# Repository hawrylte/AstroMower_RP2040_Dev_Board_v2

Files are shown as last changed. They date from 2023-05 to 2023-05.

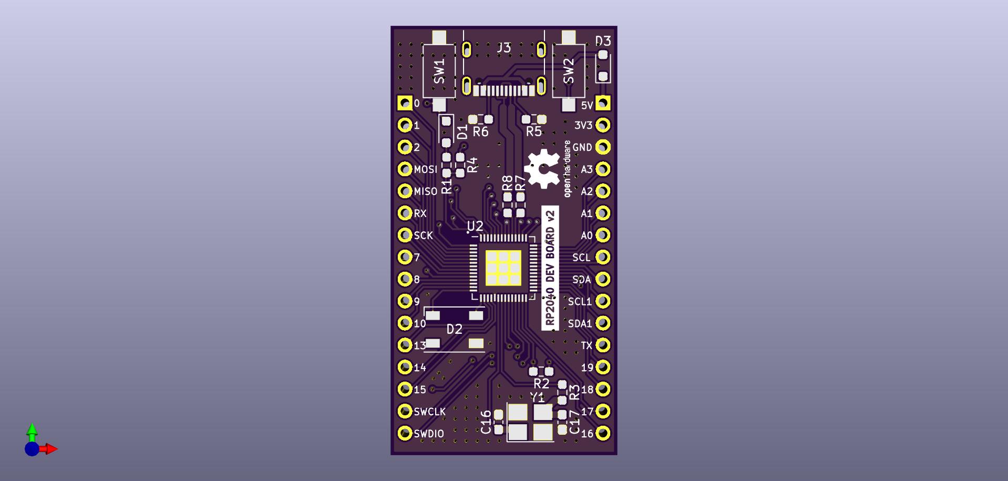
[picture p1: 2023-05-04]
images/RP2040_DevBoard_v2_front.jpg

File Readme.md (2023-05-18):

# AstroMower RP2040 Dev Board v2
## About
RP2040 Development Board to explore programming capability of Raspberry Pi [RP2040](https://www.raspberrypi.com/products/rp2040/) MCU for use in future projects.

## Hardware
  * 2 Layer PCB with parts populated on both sides

  * Spacing of pin headers is 0.9" to use on standard breadboard.

  * PCB Overall Dimensions 1.05" W X 1.95" L

  * USB-C Interface

  * Resistor and Capacitor sizes are 0603 and 0805 with hand solder footprints

  * Incorporates Neopixel addressable LED

  * 8 MB QSPI Flash

  * All parts ordered through Digi-Key

  * Developed in [KiCad 7.0](https://www.kicad.org/)

  * DRC for Manufacture through [OSHPARK](https://oshpark.com/)

## Software
### ***SOFTWARE UNDER DEVELOPMENT***
### MicroPython
MicroPython firmware for board can be downloaded directly or built from source.

***Instructions for building from source on Debian based system***

Building from source requires MicroPython source. Installation of this mirrors instructions found in Raspberry Pi [Raspberry Pi Pico Python SDK](https://datasheets.raspberrypi.com/pico/raspberry-pi-pico-python-sdk.pdf)

Create *pico* directory
```
mkdir pico
cd pico
```
Then clone the *micropython* git repository
```
git clone https://github.com/micropython/micropython.git --branch master
```
Fetch additional submodules required for a RP2 MCU board
```
cd micropython
make -C port/rp2 submodules
```
To build *micropython* additional tools are required
```
sudo apt update
sudo apt install cmake gcc-arm-none-eabi libnewlib-arm-none-eabi build-essential libstdc++-arm-none-eabi-newlib
```
Bootstrap a special tool for MicroPython builds
```
make -C mpy-cross
```
***Load Board Specific Files for AstroMower Board***

Download *AstroMower RP2040 Dev Board v2* git repository
```
cd ..
git clone https://github.com/hawrylte/AstroMower_RP2040_Dev_Board_v2.git
```
Move specific board files to proper locations in *MicroPython* source files
```
cp -r AstroMower_RP2040_Dev_Board_v2/src/ASTROMOWER_RP2040_DEV_BOARD_V2 micropython/ports/rp2/boards/ASTROMOWER_RP2040_DEV_BOARD_V2
cp -r AstroMower_RP2040_Dev_Board_v2/src/astromower_rp2040_dev_board_v2.h micropython/lib/pico-sdk/src/boards/include/boards/astromower_rp2040_dev_board_v2.h
```
Build the port we need for RP2040 and specify our particular board to be built
```
cd micropython/ports/rp2
make BOARD=ASTROMOWER_RP2040_DEV_BOARD_V2
```
Copy UF2 Firmware from *MicroPython* build directory to *pico* directory
```
cd ../../..
cp micropython/ports/rp2/build-ASTROMOWER_RP2040_DEV_BOARD_V2/firmware.uf2 AstroMower_RP2040_Dev_Board_MicroPython_firmware.uf2
```
### C/C++

***Instructions for setting up PICO-SDK from source on Debian based system***

Setting up the *pico-sdk* mirrors instructions found in Raspberry Pi [Gettting Stated with Raspberry Pi Pico](https://datasheets.raspberrypi.com/pico/getting-started-with-pico.pdf)

Create *pico* directory
```
mkdir pico
cd pico
```
Then clone the *pico-sdk* and the *pico-examples* git repositories
```
git clone http://github.com/raspberrypi/pico-sdk.git --branch master
cd pico-sdk
git submodule update --init
cd ..
git clone http://github.com/raspberrypi/pico-examples.git --branch master
```
To build *pico-examples* additional tools are required
```
sudo apt update
sudo apt install cmake gcc-arm-none-eabi libnewlib-arm-none-eabi build-essentials libstdc++-arm-none-eabi-newlib
```
Download *AstroMower RP2040 Dev Board v2* git repositiry
```
git clone https://github.com/hawrylte/AstroMower_RP2040_Dev_Board_v2.git
```
Move specific board files to proper locations in *pico-sdk* source files
```
cp -r AstroMower_RP2040_Dev_Board_v2/src/astromower_rp2040_dev_board_v2.h pico-sdk/src/boards/include/boards/astromower_rp2040_dev_board_v2.h
```
***Instructions for building Blink example from PICO-EXAMPLES from source on Debian based system***

***AstroMower Dev Board v2 does not have a discrete LED for Blink to run, but this shows the process of building a C/C++ program for the AstroMower Dev Board v2***

Change to *pico-examples* directory and make *build* directory.
```
cd pico-examples
mkdir build
cd buid
```
Set *PICO_SDK_PATH*
```
export PICO-SDK-PATH=../../pico-sdk
```
Prepare cmke build directory and identify board to build program for.
```
cmake .. -DPICO_BOARD=astromower_rp2040_dev_board_v2
cd blink
make -j4
```
*blink.elf* is used by the debugger
*blink.uf2* is the program and can be dragged onto the RP2040 USB Mass Storage Device

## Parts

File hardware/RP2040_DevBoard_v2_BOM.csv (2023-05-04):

Reference | Value | Footprint | Datasheet | Digi-Key PN | Mfg PN | Qty
C1, C2, C7 | 1u | Capacitor_SMD:C_0603_1608Metric_Pad1.08x0.95mm_HandSolder | https://datasheets.kyocera-avx.com/X7RDielectric.pdf | 478-5010-2-ND | 0603YC105KAT2A | 3
C3-C6, C8-C13, C15 | 0.1u | Capacitor_SMD:C_0603_1608Metric_Pad1.08x0.95mm_HandSolder | https://datasheets.kyocera-avx.com/X7RDielectric.pdf | 478-7018-2-ND | 06033C104KAT4A | 11
C14, C18 | 10u | Capacitor_SMD:C_0805_2012Metric_Pad1.18x1.45mm_HandSolder | https://datasheets.kyocera-avx.com/X7RDielectric.pdf | 478-10578-2-ND | 0805ZC106KAT2A | 2
C16, C17 | 8p | Capacitor_SMD:C_0603_1608Metric_Pad1.08x0.95mm_HandSolder | https://datasheets.kyocera-avx.com/AutoMLCC.pdf | 478-9370-2-ND | 06031A8R0D4T2A | 2
D1, D3 | NSR0320 | Diode_SMD:D_SOD-323_HandSoldering | https://www.onsemi.com/pdf/datasheet/nsr0320mw2t1-d.pdf | NSR0320MW2T3GOSTR-ND | NSR0320MW2T3G | 2
D2 | WS2812B | RP2040_DevBoard:WS2812B | http://cdn.sparkfun.com/datasheets/BreakoutBoards/WS2812B.pdf | 1568-COM-16347TR-ND | COM-16347 | 1
J1, J2 | Conn_01x16 | Connector_PinHeader_2.54mm:PinHeader_1x16_P2.54mm_Vertical | https://app.adam-tech.com/products/download/data_sheet/201605/ph1-xx-ua-data-sheet.pdf | 2057-PH1-16-UA-ND | PH1-16-UA | 2
J3 | USB_C_Receptacle_USB2.0 | Connector_USB:USB_C_Receptacle_GCT_USB4105-xx-A_16P_TopMnt_Horizontal | https://media.digikey.com/pdf/Data%20Sheets/GCT%20PDFs/USB4105%20-%20Product%20Drawing.pdf | 2073-USB4105-GF-ATR-ND | USB4105-GF-A | 1
R1, R3 | 1k3 | Resistor_SMD:R_0603_1608Metric_Pad0.98x0.95mm_HandSolder | https://industrial.panasonic.com/cdbs/www-data/pdf/RDA0000/AOA0000C304.pdf | P1.30KHTR-ND | ERJ-3EKF1301V | 2
R2, R4 | 10k | Resistor_SMD:R_0603_1608Metric_Pad0.98x0.95mm_HandSolder | https://industrial.panasonic.com/cdbs/www-data/pdf/RDA0000/AOA0000C304.pdf | P10.0KHTR-ND | ERJ-3EKF1002V | 2
R5, R6 | 5k1 | Resistor_SMD:R_0603_1608Metric_Pad0.98x0.95mm_HandSolder | https://industrial.panasonic.com/cdbs/www-data/pdf/RDA0000/AOA0000C304.pdf | P5.10KHTR-ND | ERJ-3EKF5101V | 2
R7, R8 | 27 | Resistor_SMD:R_0603_1608Metric_Pad0.98x0.95mm_HandSolder | https://industrial.panasonic.com/cdbs/www-data/pdf/RDA0000/AOA0000C304.pdf | P27.0HTR-ND | ERJ-3EKF27R0V | 2
SW1, SW2 | PTS636 SK25 | Button_Switch_SMD:SW_SPST_CK_RS282G05A3 | https://www.ckswitches.com/media/2779/pts636.pdf | CKN12322-2-ND | PTS636 SK25 SMTR LFS | 2
U1 | AP2112K-3.3 | Package_TO_SOT_SMD:SOT-23-5 | https://www.diodes.com/assets/Datasheets/AP2112.pdf | AP2112K-3.3TRG1DITR-ND | AP2112K-3.3TRG1 | 1
U2 | RP2040 | Package_DFN_QFN:QFN-56-1EP_7x7mm_P0.4mm_EP4x4mm | https://datasheets.raspberrypi.com/rp2040/rp2040-datasheet.pdf | 2648-SC0914(13)TR-ND | SC0914(13) | 1
U3 | W25Q64JVSS | Package_SO:SOIC-8_5.23x5.23mm_P1.27mm | https://www.winbond.com/resource-files/w25q64jv%20revj%2003272018%20plus.pdf | W25Q64JVSSIQ-ND | W25Q64JVSSIQ | 1
Y1 | 12MHz | Crystal:Crystal_SMD_3225-4Pin_3.2x2.5mm_HandSoldering | https://www.we-online.com/catalog/datasheet/830108206909.pdf | 1923-830108206909TR-ND | 830108206909 | 1

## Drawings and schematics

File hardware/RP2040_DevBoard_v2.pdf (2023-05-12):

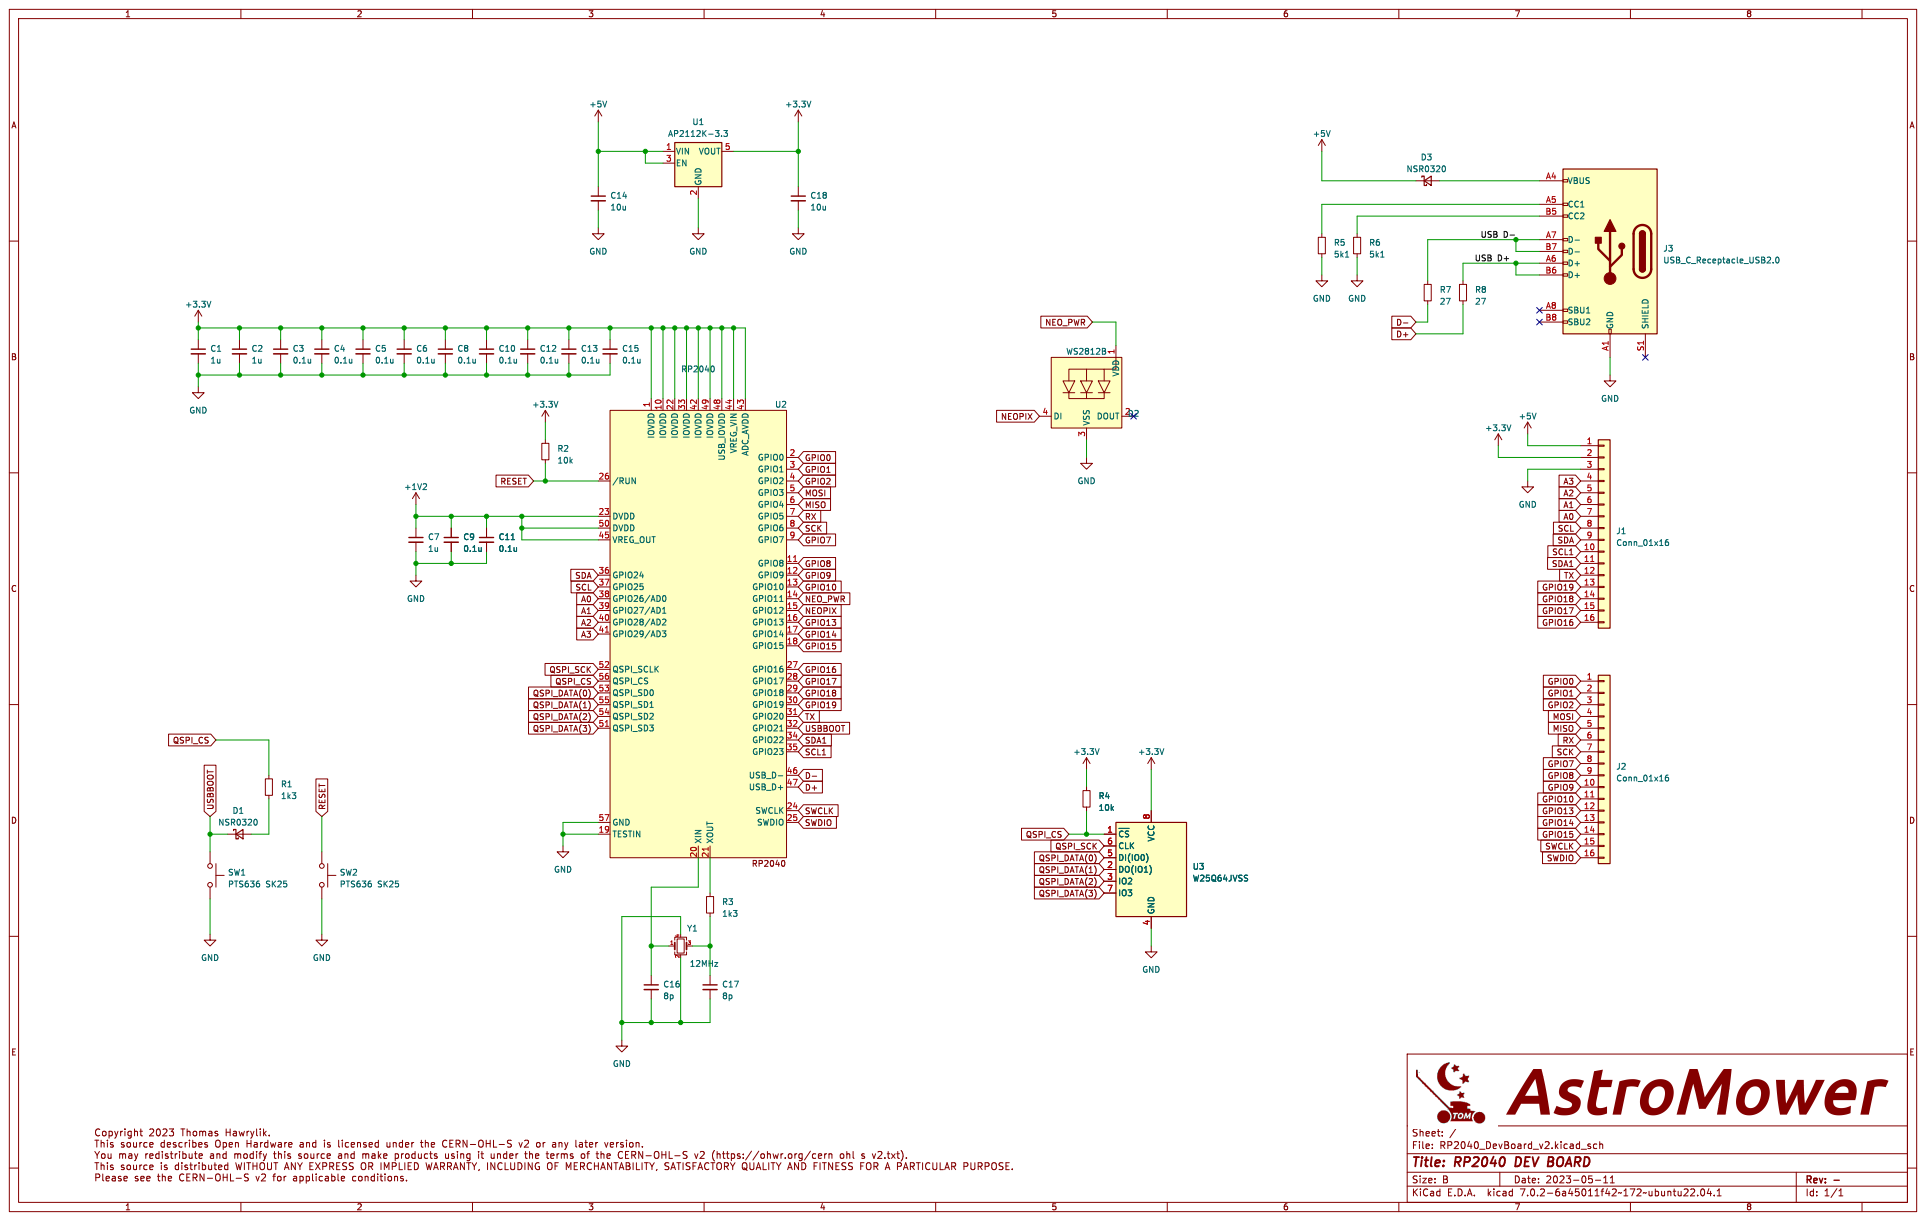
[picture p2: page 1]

2 EN 3 VOUT 5 U1 AP2112K-3.3 GND GND GND

1 IOVDD 10 GPIO8 11 GPIO9 12 GPIO10 13 GPIO11 14 GPIO12 15 GPIO13 16 GPIO14 17 GPIO15 18 TESTIN 19 GPIO0 2 XIN 20 XOUT 21 IOVDD 22 DVDD 23 SWCLK 24 SWDIO 25

Id: 1/1 Title: RP2040 DEV BOARD

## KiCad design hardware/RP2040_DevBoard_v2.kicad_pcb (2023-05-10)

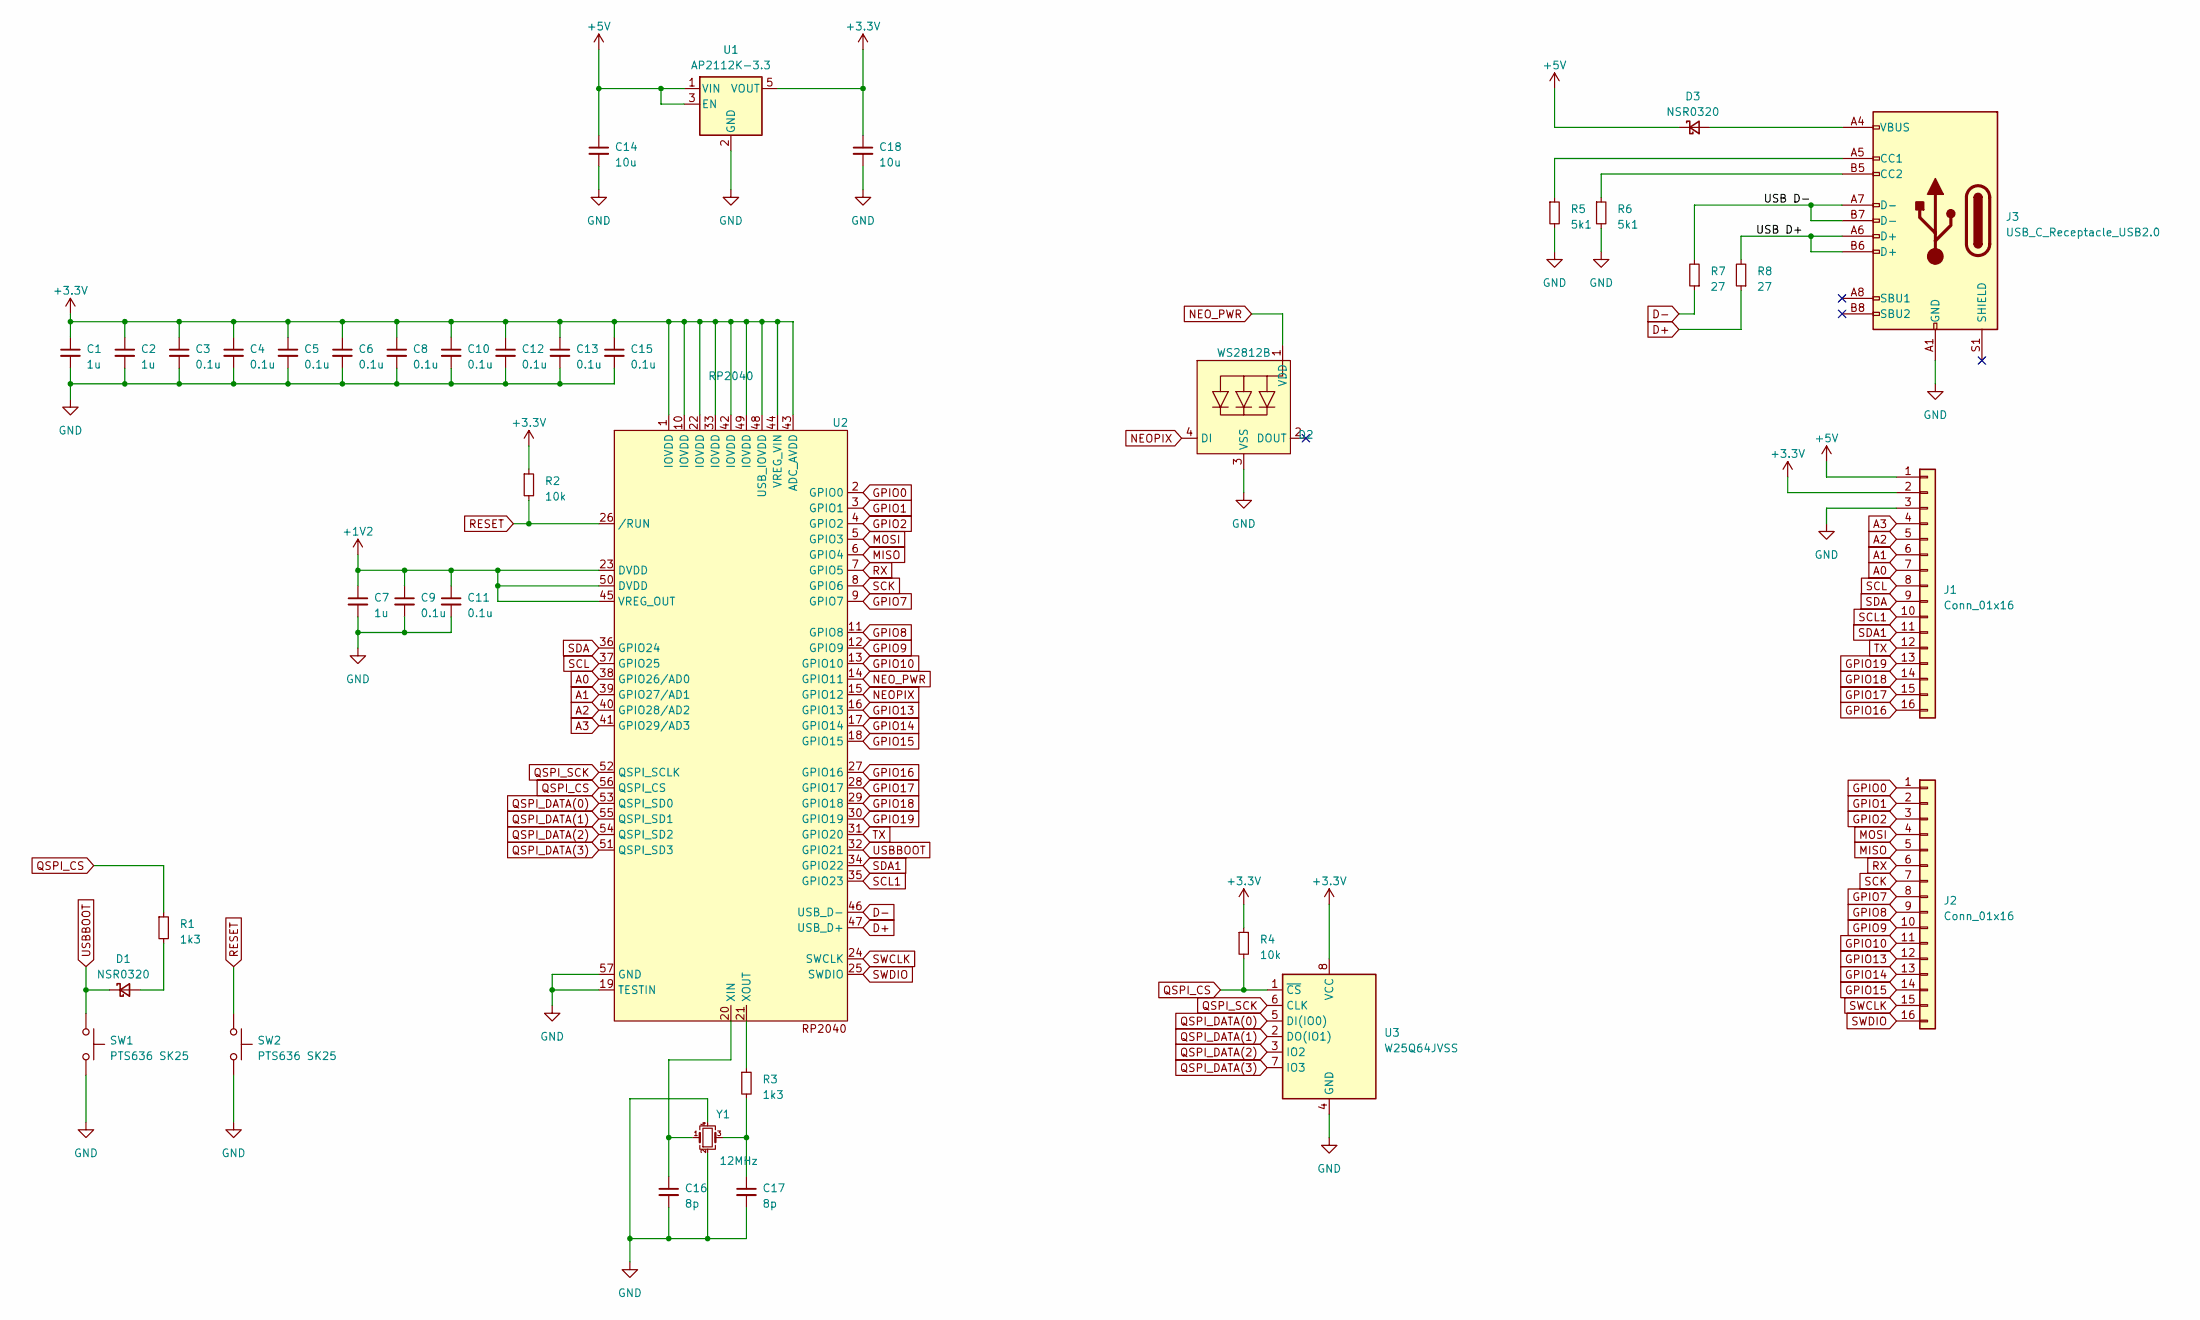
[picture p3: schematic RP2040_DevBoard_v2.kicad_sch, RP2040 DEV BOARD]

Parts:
C1, C2, C7: 1u; C_0603_1608Metric_Pad1.08x0.95mm_HandSolder; Mfg PN 0603YC105KAT2A; Digi-Key PN 478-5010-2-ND
C3, C4, C5, C6, C8, C9, C10, C11, C12, C13, C15: 0.1u; C_0603_1608Metric_Pad1.08x0.95mm_HandSolder; Mfg PN 06033C104KAT4A; Digi-Key PN 478-7018-2-ND
C14, C18: 10u; C_0805_2012Metric_Pad1.18x1.45mm_HandSolder; Mfg PN 0805ZC106KAT2A; Digi-Key PN 478-10578-2-ND
C16, C17: 8p; C_0603_1608Metric_Pad1.08x0.95mm_HandSolder; Mfg PN 06031A8R0D4T2A; Digi-Key PN 478-9370-2-ND
D1, D3: NSR0320; D_SOD-323_HandSoldering; Mfg PN NSR0320MW2T3G; Digi-Key PN NSR0320MW2T3GOSTR-ND
D2: WS2812B; Mfg PN COM-16347; Digi-Key PN 1568-COM-16347TR-ND
J1, J2: Conn_01x16; PinHeader_1x16_P2.54mm_Vertical; Mfg PN PH1-16-UA; Digi-Key PN 2057-PH1-16-UA-ND
J3: USB_C_Receptacle_USB2.0; USB_C_Receptacle_GCT_USB4105-xx-A_16P_TopMnt_Horizontal; Mfg PN USB4105-GF-A; Digi-Key PN 2073-USB4105-GF-ATR-ND
R1, R3: 1k3; R_0603_1608Metric_Pad0.98x0.95mm_HandSolder; Mfg PN ERJ-3EKF1301V; Digi-Key PN P1.30KHTR-ND
R2, R4: 10k; R_0603_1608Metric_Pad0.98x0.95mm_HandSolder; Mfg PN ERJ-3EKF1002V; Digi-Key PN P10.0KHTR-ND
R5, R6: 5k1; R_0603_1608Metric_Pad0.98x0.95mm_HandSolder; Mfg PN ERJ-3EKF5101V; Digi-Key PN P5.10KHTR-ND
R7, R8: 27; R_0603_1608Metric_Pad0.98x0.95mm_HandSolder; Mfg PN ERJ-3EKF27R0V; Digi-Key PN P27.0HTR-ND
SW1, SW2: PTS636 SK25; SW_SPST_CK_RS282G05A3; Mfg PN PTS636 SK25 SMTR LFS; Digi-Key PN CKN12322-2-ND
U1: AP2112K-3.3; SOT-23-5; Mfg PN AP2112K-3.3TRG1; Digi-Key PN AP2112K-3.3TRG1DITR-ND
U2: RP2040; QFN-56-1EP_7x7mm_P0.4mm_EP4x4mm; Mfg PN SC0914(13); Digi-Key PN 2648-SC0914(13)TR-ND
U3: W25Q64JVSS; SOIC-8_5.23x5.23mm_P1.27mm; Mfg PN W25Q64JVSSIQ; Digi-Key PN W25Q64JVSSIQ-ND
Y1: 12MHz; Crystal_SMD_3225-4Pin_3.2x2.5mm_HandSoldering; Mfg PN 830108206909; Digi-Key PN 1923-830108206909TR-ND

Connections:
+1V2: C7.1, C9.1, C11.1, U2.23 (DVDD), U2.45 (VREG_OUT), U2.50 (DVDD)
+3.3V: C1.1, C2.1, C3.1, C4.1, C5.1, C6.1, C8.1, C10.1, C12.1, C13.1, C15.1, C18.1, J1.2, R2.1, R4.1, U1.5 (VOUT), U2.1 (IOVDD), U2.10 (IOVDD), U2.22 (IOVDD), U2.33 (IOVDD), U2.42 (IOVDD), U2.43 (ADC_AVDD), U2.44 (VREG_VIN), U2.48 (USB_IOVDD), U2.49 (IOVDD), U3.8 (VCC)
+5V: C14.1, D3.1 (K), J1.1, U1.1 (VIN), U1.3 (EN)
/USB D+: J3.A6 (D+), J3.B6 (D+), R8.2
/USB D-: J3.A7 (D-), J3.B7 (D-), R7.2
A0: J1.7, U2.38 (GPIO26/AD0)
A1: J1.6, U2.39 (GPIO27/AD1)
A2: J1.5, U2.40 (GPIO28/AD2)
A3: J1.4, U2.41 (GPIO29/AD3)
D+: R8.1, U2.47 (USB_D+)
D-: R7.1, U2.46 (USB_D-)
GND: C1.2, C2.2, C3.2, C4.2, C5.2, C6.2, C7.2, C8.2, C9.2, C10.2, C11.2, C12.2, C13.2, C14.2, C15.2, C16.2, C17.2, C18.2, D2.3 (VSS), J1.3, J3.A1 (GND), J3.A12 (GND), J3.B1 (GND), J3.B12 (GND), R5.2, R6.2, SW1.2 (B), SW2.2 (B), U1.2 (GND), U2.19 (TESTIN), U2.57 (GND), U3.4 (GND), Y1.2, Y1.4
GPIO0: J2.1, U2.2 (GPIO0)
GPIO1: J2.2, U2.3 (GPIO1)
GPIO2: J2.3, U2.4 (GPIO2)
GPIO7: J2.8, U2.9 (GPIO7)
GPIO8: J2.9, U2.11 (GPIO8)
GPIO9: J2.10, U2.12 (GPIO9)
GPIO10: J2.11, U2.13 (GPIO10)
GPIO13: J2.12, U2.16 (GPIO13)
GPIO14: J2.13, U2.17 (GPIO14)
GPIO15: J2.14, U2.18 (GPIO15)
GPIO16: J1.16, U2.27 (GPIO16)
GPIO17: J1.15, U2.28 (GPIO17)
GPIO18: J1.14, U2.29 (GPIO18)
GPIO19: J1.13, U2.30 (GPIO19)
MISO: J2.5, U2.6 (GPIO4)
MOSI: J2.4, U2.5 (GPIO3)
NEOPIX: D2.4 (DI), U2.15 (GPIO12)
NEO_PWR: D2.1 (VDD), U2.14 (GPIO11)
unnamed: C17.1, R3.2, Y1.3
unnamed: D1.2 (A), R1.2
unnamed: D3.2 (A), J3.A4 (VBUS), J3.A9 (VBUS), J3.B4 (VBUS), J3.B9 (VBUS)
unnamed: J3.A5 (CC1), R5.1
unnamed: J3.B5 (CC2), R6.1
unnamed: C16.1, U2.20 (XIN), Y1.1
unnamed: R3.1, U2.21 (XOUT)
QSPI_CS: R1.1, R4.2, U2.56 (QSPI_CS), U3.1 (~CS)
QSPI_DATA(0): U2.53 (QSPI_SD0), U3.5 (DI(IO0))
QSPI_DATA(1): U2.55 (QSPI_SD1), U3.2 (DO(IO1))
QSPI_DATA(2): U2.54 (QSPI_SD2), U3.3 (IO2)
QSPI_DATA(3): U2.51 (QSPI_SD3), U3.7 (IO3)
QSPI_SCK: U2.52 (QSPI_SCLK), U3.6 (CLK)
RESET: R2.2, SW2.1 (A), U2.26 (/RUN)
RX: J2.6, U2.7 (GPIO5)
SCK: J2.7, U2.8 (GPIO6)
SCL: J1.8, U2.37 (GPIO25)
SCL1: J1.10, U2.35 (GPIO23)
SDA: J1.9, U2.36 (GPIO24)
SDA1: J1.11, U2.34 (GPIO22)
SWCLK: J2.15, U2.24 (SWCLK)
SWDIO: J2.16, U2.25 (SWDIO)
TX: J1.12, U2.31 (GPIO20)
USBBOOT: D1.1 (K), SW1.1 (A), U2.32 (GPIO21)

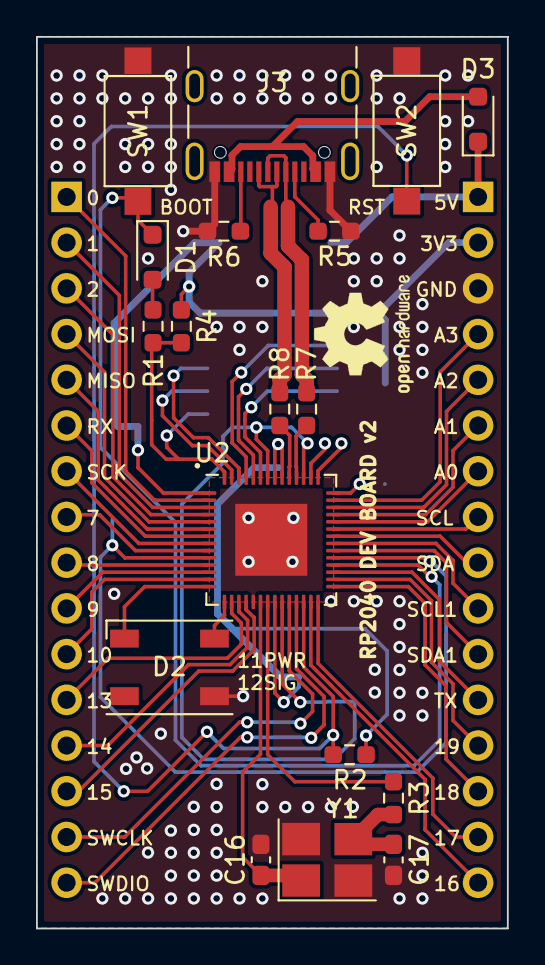
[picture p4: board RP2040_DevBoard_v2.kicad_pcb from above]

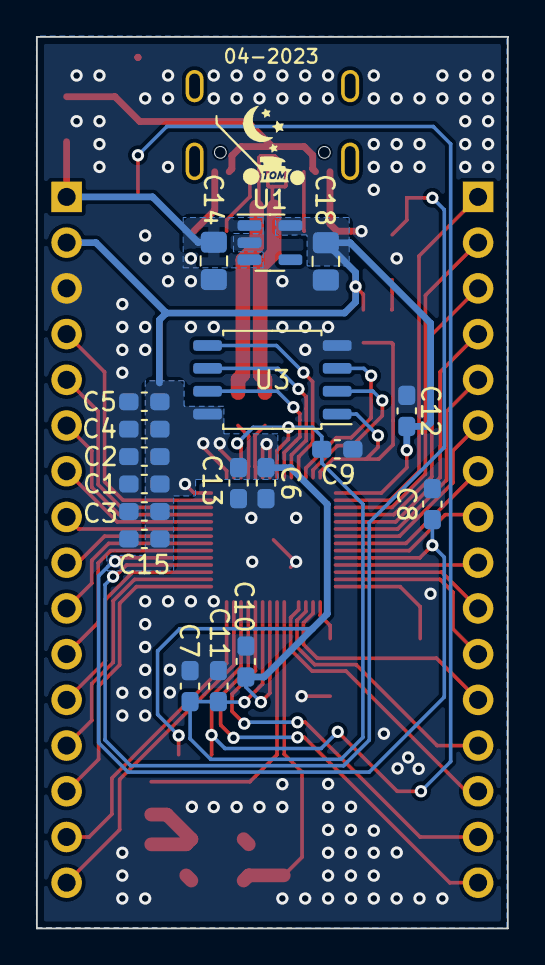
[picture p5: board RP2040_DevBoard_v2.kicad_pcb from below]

Board: 2 copper layers, 26.2 x 49.5 mm, 38 parts (20 on the bottom side), 54 nets.

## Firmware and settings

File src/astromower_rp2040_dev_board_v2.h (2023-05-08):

/* AstroMower RP2040 Dev Board v2

Copyright 2023 Thomas Hawryik

Permission is hereby granted, free of charge, to any person obtaining a copy of this software and associated documentation files (the “Software”), to deal in the Software without restriction, including without limitation the rights to use, copy, modify, merge, publish, distribute, sublicense, and/or sell copies of the Software, and to permit persons to whom the Software is furnished to do so, subject to the following conditions:

The above copyright notice and this permission notice shall be included in all copies or substantial portions of the Software.

THE SOFTWARE IS PROVIDED “AS IS”, WITHOUT WARRANTY OF ANY KIND, EXPRESS OR IMPLIED, INCLUDING BUT NOT LIMITED TO THE WARRANTIES OF MERCHANTABILITY, FITNESS FOR A PARTICULAR PURPOSE AND NONINFRINGEMENT. IN NO EVENT SHALL THE AUTHORS OR COPYRIGHT HOLDERS BE LIABLE FOR ANY CLAIM, DAMAGES OR OTHER LIABILITY, WHETHER IN AN ACTION OF CONTRACT, TORT OR OTHERWISE, ARISING FROM, OUT OF OR IN CONNECTION WITH THE SOFTWARE OR THE USE OR OTHER DEALINGS IN THE SOFTWARE.

*/

// -----------------------------------------------------
// NOTE: THIS HEADER IS ALSO INCLUDED BY ASSEMBLER SO
//       SHOULD ONLY CONSIST OF PREPROCESSOR DIRECTIVES
// -----------------------------------------------------
// Board definition for the ASTROMOWER_RP2040_DEV_BOARD_V2
//
// This header may be included by other board headers as "boards/astromower_rp2040_dev_board_v2.h"

#ifndef _BOARDS_ASTROMOWER_RP2040_DEV_BOARD_V2
#define _BOARDS_ASTROMOWER_RP2040_DEV_BOARD_V2
// For board detection
#define ASTROMOWER_RP2040_DEV_BOARD_V2

// On some samples, the xosc can take longer to stabilize than is usual
#ifndef PICO_XOSC_STARTUP_DELAY_MULTIPLIER
#define PICO_XOSC_STARTUP_DELAY_MULTIPLIER 64
#endif

//------------- UART -------------//
#ifndef PICO_DEFAULT_UART
#define PICO_DEFAULT_UART 1
#endif

#ifndef PICO_DEFAULT_UART_TX_PIN
#define PICO_DEFAULT_UART_TX_PIN 20
#endif

#ifndef PICO_DEFAULT_UART_RX_PIN
#define PICO_DEFAULT_UART_RX_PIN 5
#endif

//------------- LED -------------//
// No normal LED
// #define PICO_DEFAULT_LED_PIN 13

#ifndef PICO_DEFAULT_WS2812_PIN
#define PICO_DEFAULT_WS2812_PIN 12
#endif

#ifndef PICO_DEFAULT_WS2812_POWER_PIN
#define PICO_DEFAULT_WS2812_POWER_PIN 11
#endif

//------------- I2C -------------//
#ifndef PICO_DEFAULT_I2C
#define PICO_DEFAULT_I2C 0
#endif

#ifndef PICO_DEFAULT_I2C_SDA_PIN
#define PICO_DEFAULT_I2C_SDA_PIN 24
#endif

#ifndef PICO_DEFAULT_I2C_SCL_PIN
#define PICO_DEFAULT_I2C_SCL_PIN 25
#endif

//------------- SPI -------------//
#ifndef PICO_DEFAULT_SPI
#define PICO_DEFAULT_SPI 0
#endif

#ifndef PICO_DEFAULT_SPI_TX_PIN
#define PICO_DEFAULT_SPI_TX_PIN 3
#endif

#ifndef PICO_DEFAULT_SPI_RX_PIN
#define PICO_DEFAULT_SPI_RX_PIN 4
#endif

#ifndef PICO_DEFAULT_SPI_SCK_PIN
#define PICO_DEFAULT_SPI_SCK_PIN 6
#endif

//------------- FLASH -------------//

#define PICO_BOOT_STAGE2_CHOOSE_W25Q080 1

#ifndef PICO_FLASH_SPI_CLKDIV
#define PICO_FLASH_SPI_CLKDIV 2
#endif

#ifndef PICO_FLASH_SIZE_BYTES
#define PICO_FLASH_SIZE_BYTES (8 * 1024 * 1024)
#endif

// All boards have B1 RP2040
#ifndef PICO_RP2040_B0_SUPPORTED
#define PICO_RP2040_B0_SUPPORTED 0
#endif

#endif
